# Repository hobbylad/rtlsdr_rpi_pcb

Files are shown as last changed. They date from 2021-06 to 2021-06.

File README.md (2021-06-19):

# rtlsdr_rpi_pcb

##RTL-SDR and Raspberry Pi 3 Carrier PCB 

An RTL-SDR and Raspberry Pi make a good combination. The RTL-SDR has a range of 24MHz-1.7GHz and the RPi 3 enough power to compile and run a wide range of open-source receiver software.

The aim of this carrier PCB is to mechanically combine both SDR and RPi, reduce wiring, allow the control of external devices such as relays and provide power with some expansion capability. Safety, noise and RPI cooling were also considerations.

The board was designed with Kicad on a single-sided board with the aim of keeping the PCB as simple as possible for hobbyists to construct with chemical etching or a milling machine.

See the [blog page for this project](https://hobbylad.wordpress.com/2021/06/17/rtl-sdr-raspberry-pi-carrier-pcb/).

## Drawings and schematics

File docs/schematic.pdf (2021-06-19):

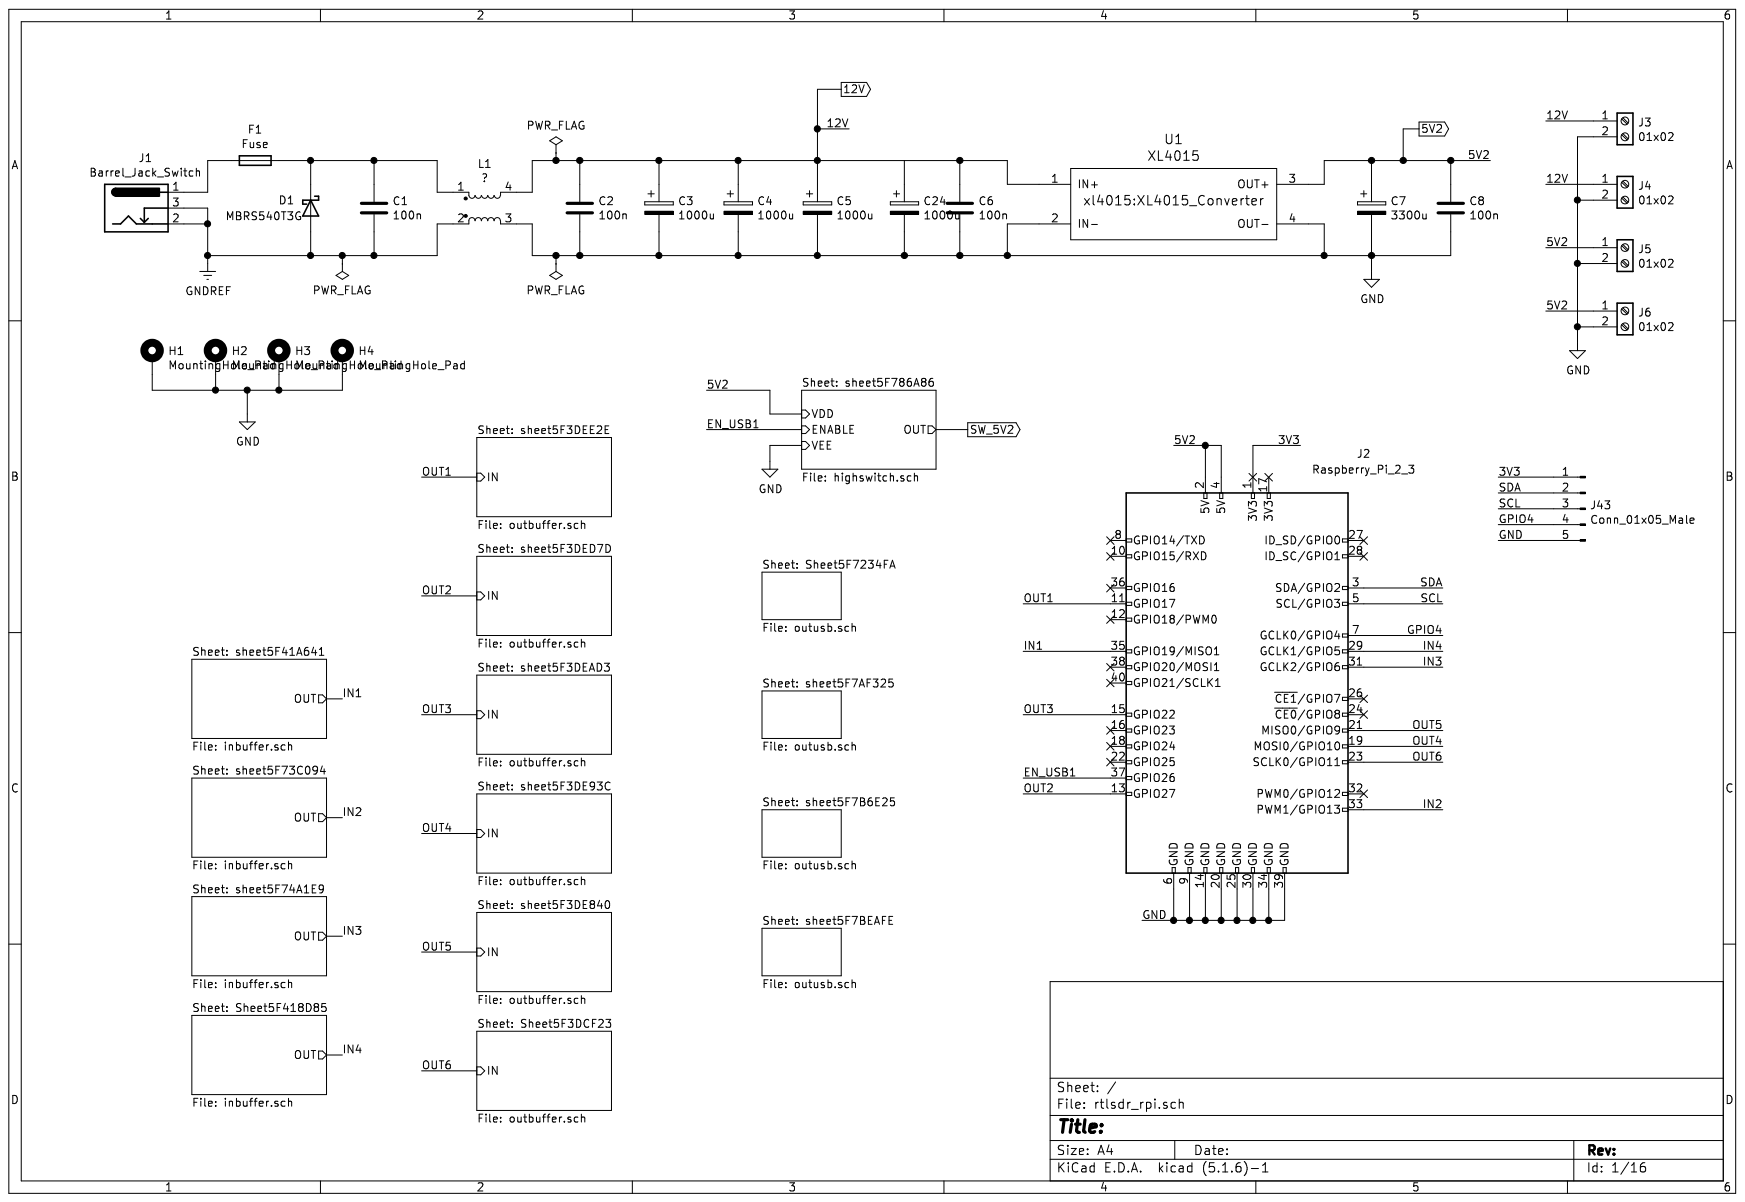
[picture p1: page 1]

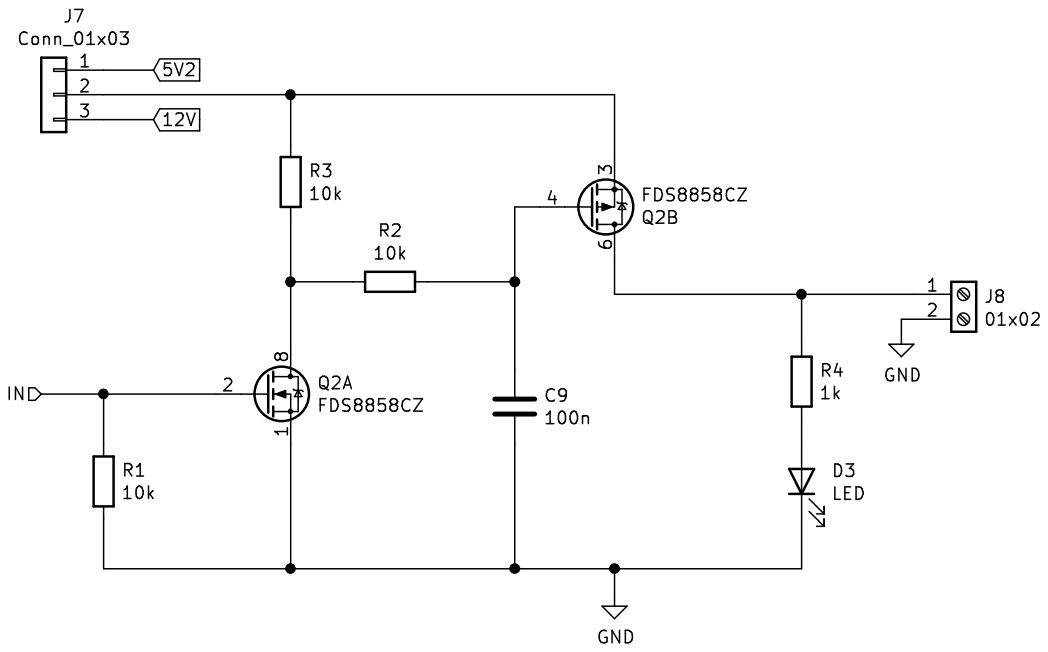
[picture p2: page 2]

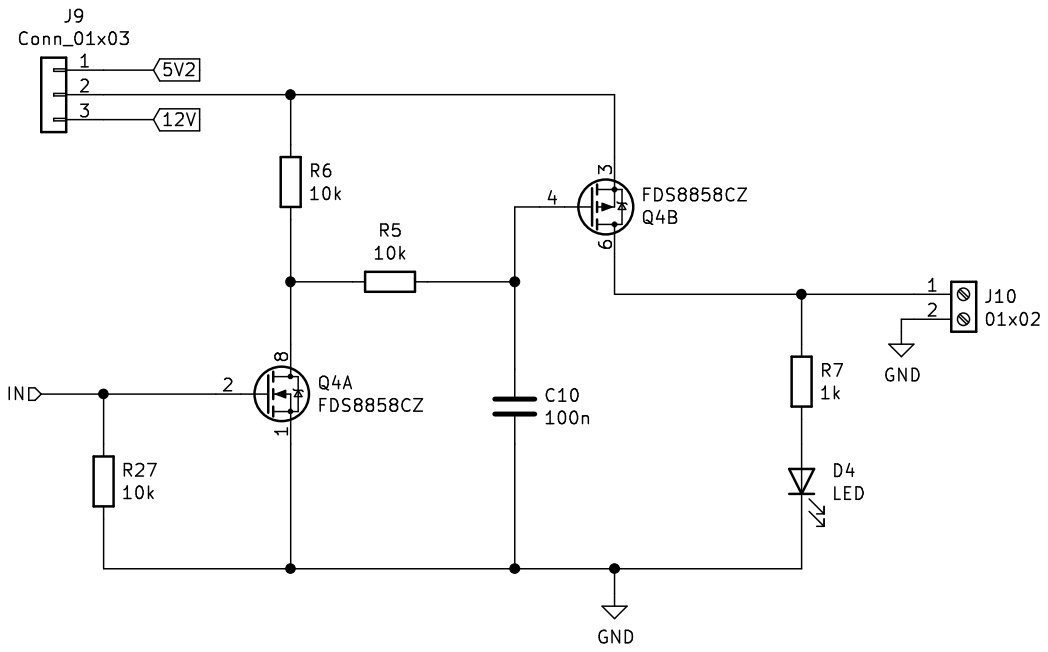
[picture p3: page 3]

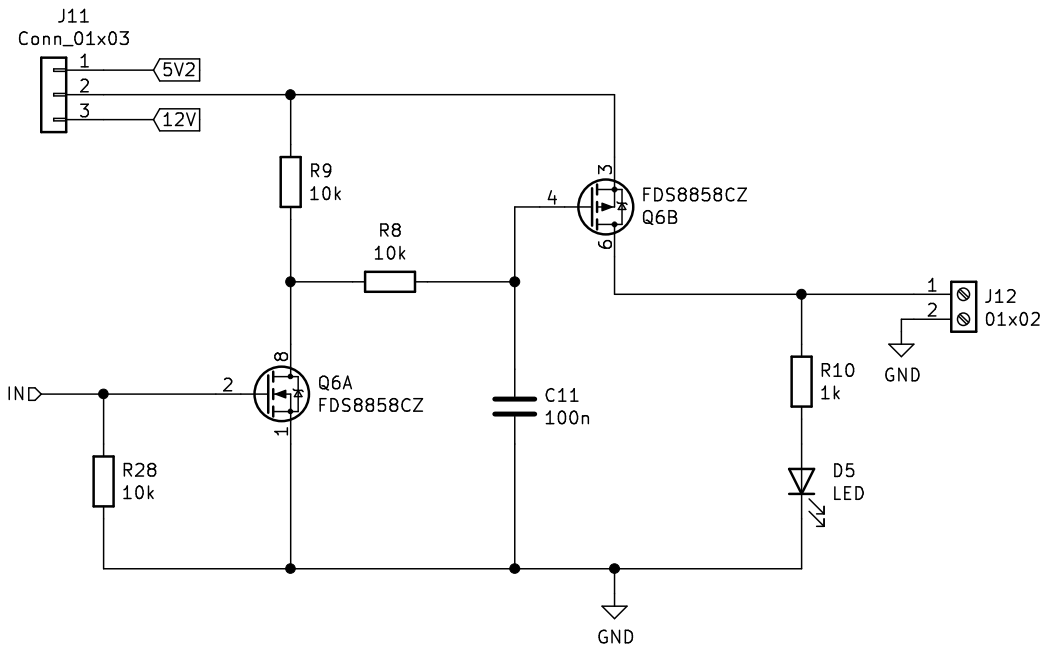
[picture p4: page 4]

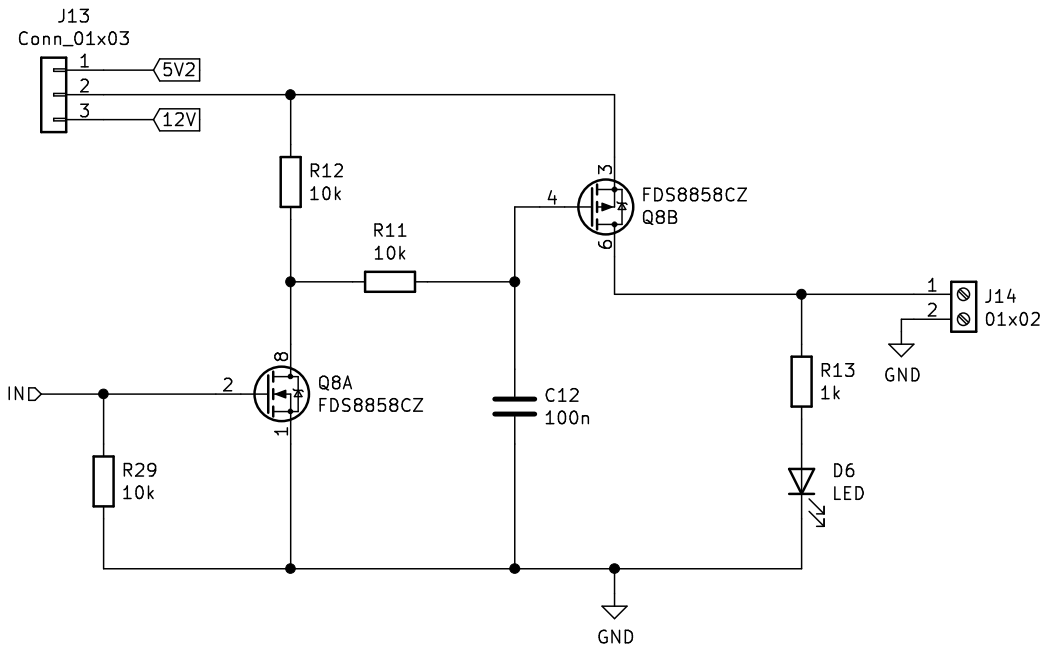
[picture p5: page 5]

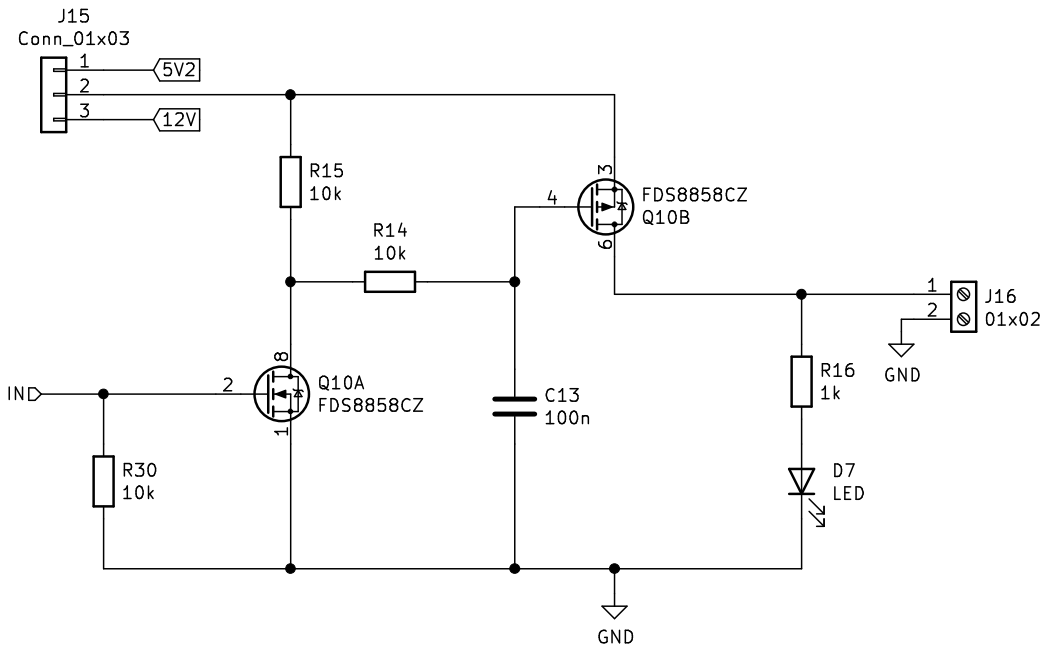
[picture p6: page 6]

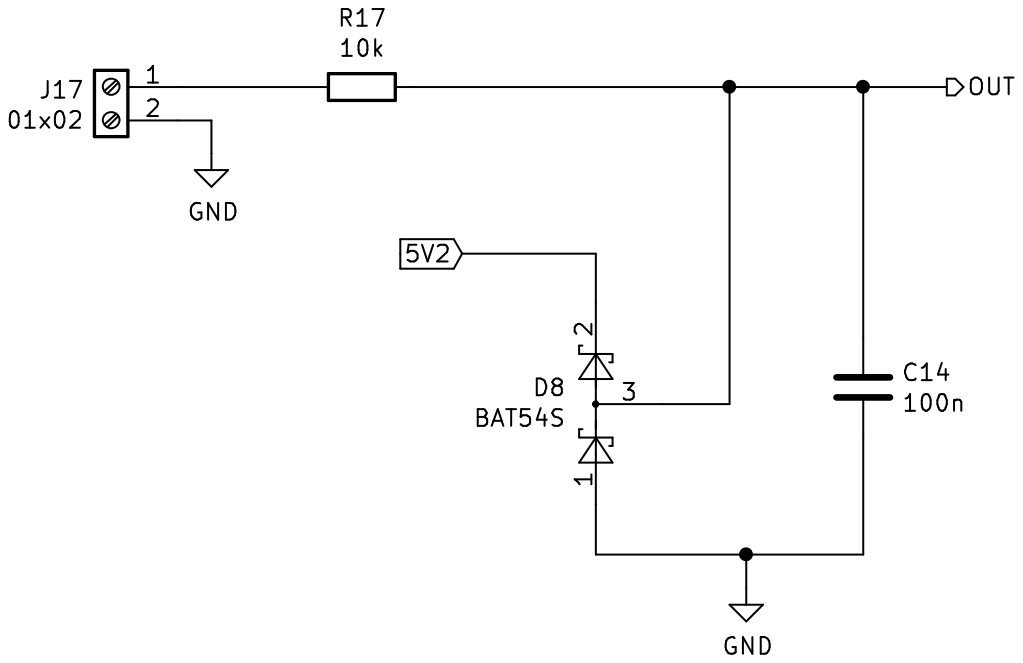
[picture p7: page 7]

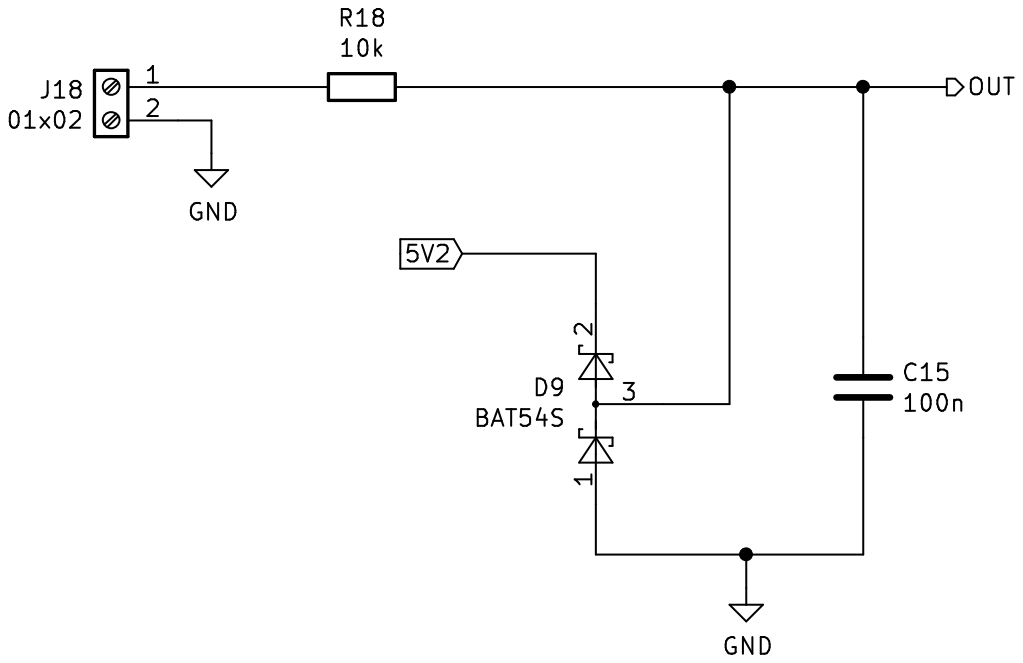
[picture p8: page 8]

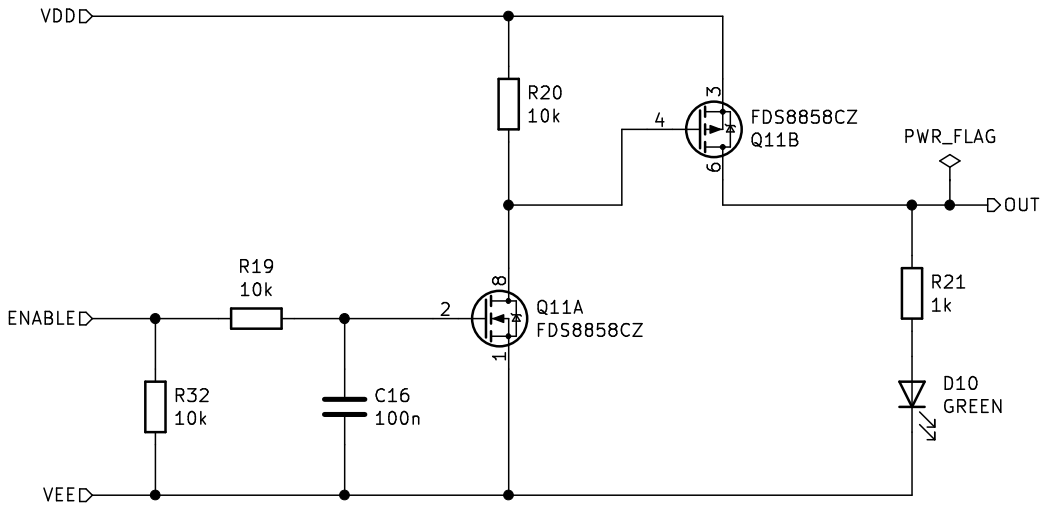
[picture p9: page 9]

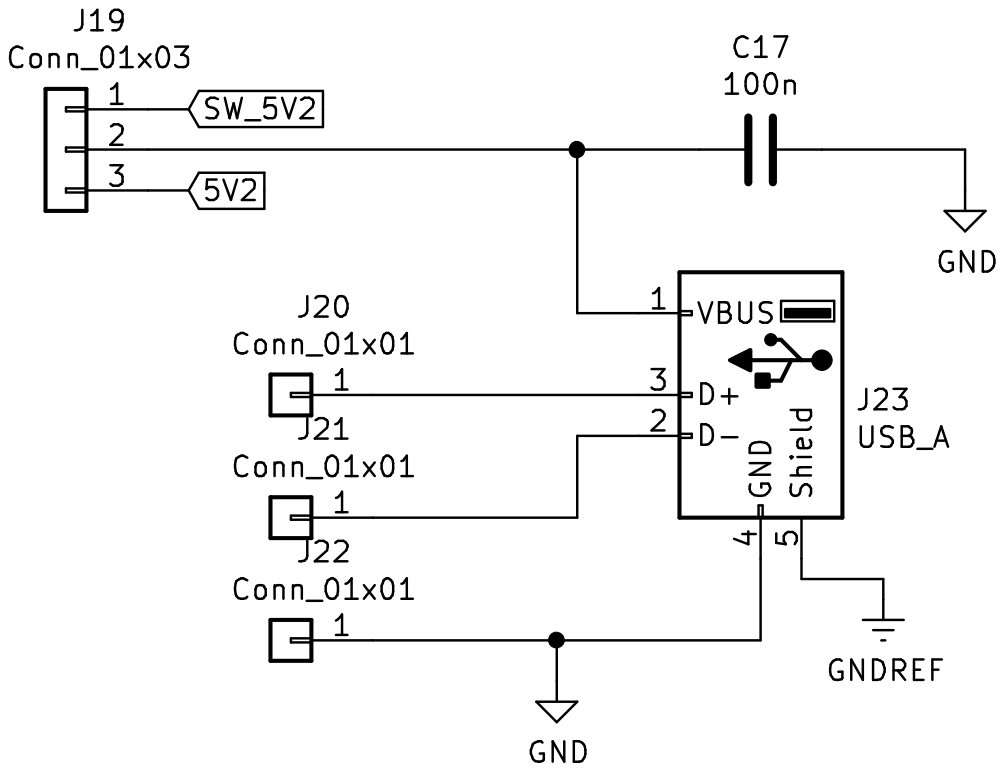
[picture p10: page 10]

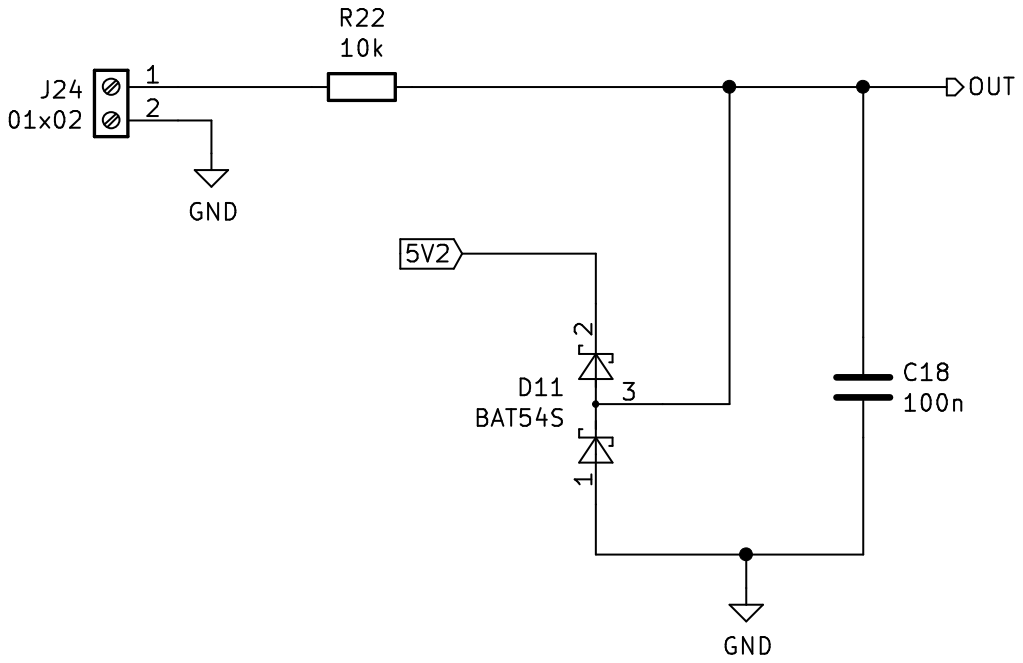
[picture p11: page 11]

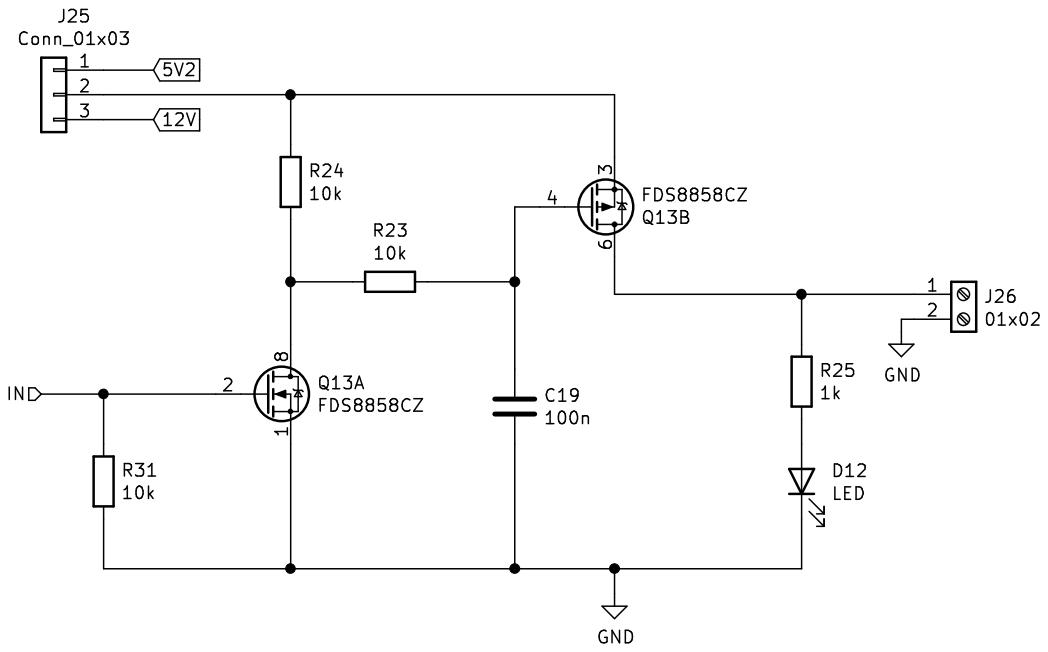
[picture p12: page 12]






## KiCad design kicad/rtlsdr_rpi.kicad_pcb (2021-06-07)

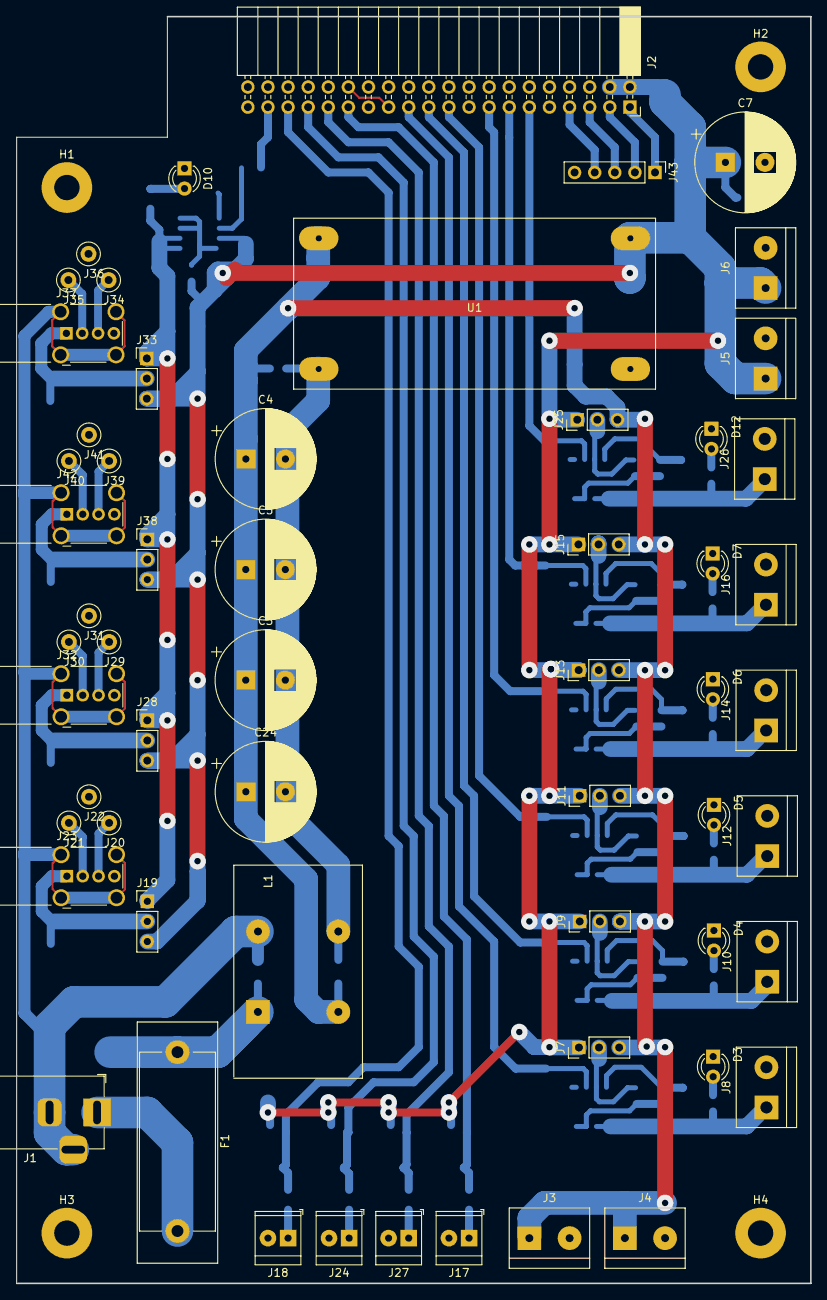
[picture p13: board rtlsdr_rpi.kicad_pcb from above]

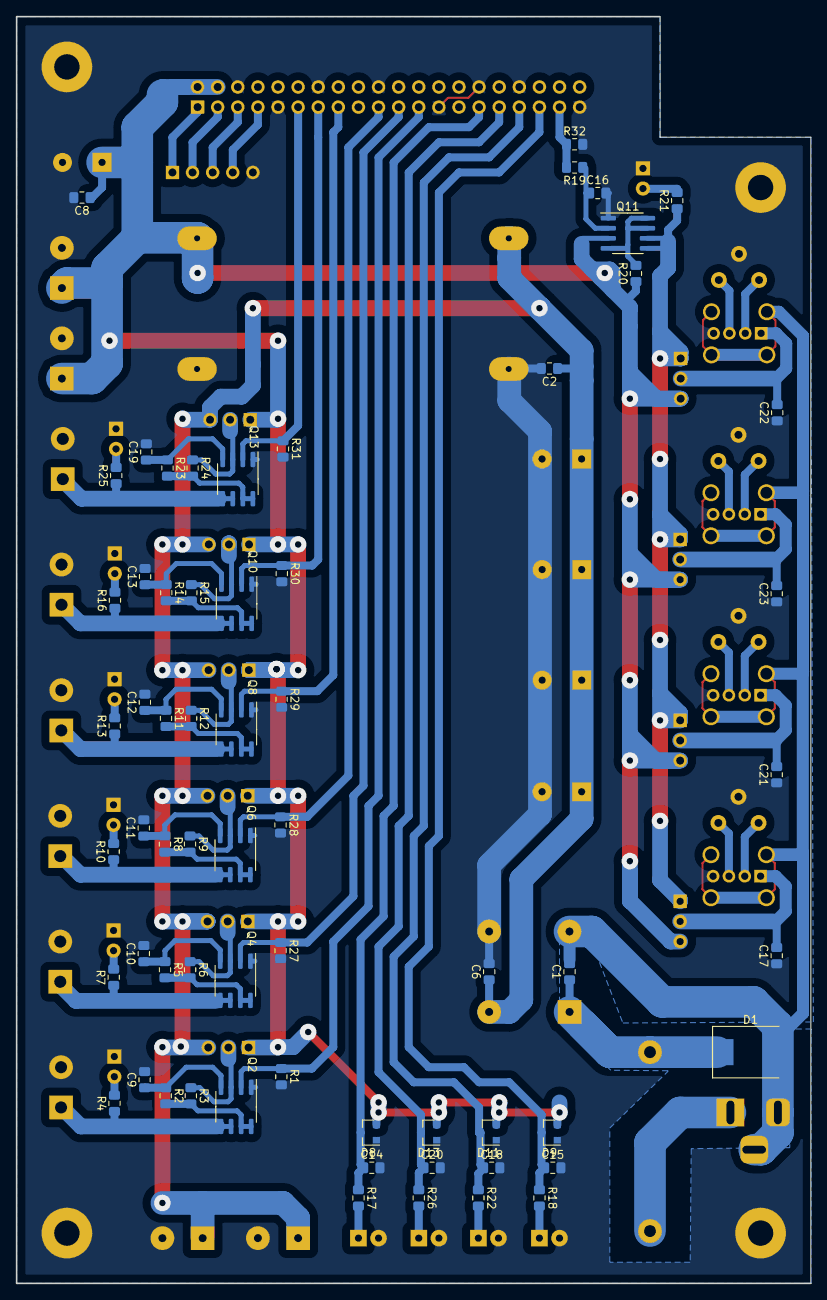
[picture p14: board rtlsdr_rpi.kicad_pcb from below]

Board: 2 copper layers, 100.3 x 160.0 mm, 125 parts (63 on the bottom side), 71 nets.

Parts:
C1, C2, C6, C8, C9, C10, C11, C12, C13, C14, C15, C16, C17, C18, C19, C20, C21, C22, C23: 100n; C_0805_2012Metric_Pad1.15x1.40mm_HandSolder
C3, C4, C5, C24: 1000u; CP_Radial_D12.5mm_P5.00mm
C7: 3300u; CP_Radial_D12.5mm_P5.00mm
D1: MBRS540T3G; D_SMC
D3, D4, D5, D6, D7, D12: LED; LED_D3.0mm
D8, D9, D11, D13: BAT54S; SOT-23
D10: GREEN; LED_D3.0mm
F1: Fuse; Fuseholder_Cylinder-5x20mm_Stelvio-Kontek_PTF78_Horizontal_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
H1, H2, H3, H4: MountingHole_Pad; MountingHole_3.2mm_M3_Pad
J1: Barrel_Jack_Switch; BarrelJack_Horizontal
J2: Raspberry_Pi_2_3; PinSocket_2x20_P2.54mm_Horizontal
J3, J4, J5, J6, J8, J10, J12, J14, J16, J26: 01x02; TerminalBlock_bornier-2_P5.08mm
J7, J9, J11, J13, J15, J19, J25, J28, J33, J38: Conn_01x03; PinHeader_1x03_P2.54mm_Vertical
J17, J18, J24, J27: 01x02; TerminalBlock_TE_282834-2_1x02_P2.54mm_Horizontal
J20, J21, J22, J29, J30, J31, J34, J35, J36, J39, J40, J41: Conn_01x01; TestPoint_Loop_D2.50mm_Drill1.0mm_LowProfile
J23, J32, J37, J42: USB_A; USB_A_Wuerth_614004134726_Horizontal
J43: Conn_01x05_Male; PinHeader_1x05_P2.54mm_Vertical
L1: ?; L_CommonMode_Toroid_Vertical_L26mm_W12mm_Px10mm_Py10mm_Ebay
Q2, Q4, Q6, Q8, Q10, Q11, Q13: FDS8858CZ; SOIC-8_3.9x4.9mm_P1.27mm
R1, R2, R3, R5, R6, R8, R9, R11, R12, R14, R15, R17, R18, R19, R20, R22, R23, R24, R26, R27, R28, R29, R30, R31, R32: 10k; R_0805_2012Metric_Pad1.15x1.40mm_HandSolder
R4, R7, R10, R13, R16, R21, R25: 1k; R_0805_2012Metric_Pad1.15x1.40mm_HandSolder
U1: XL4015; XL4015_Converter

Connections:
5V2: C7.1, C8.1, D8.2, D9.2, D11.2, D13.2, J2.2, J2.4, J5.1, J6.1, J7.1, J9.1, J11.1, J13.1, J15.1, J19.3, J25.1, J28.3, J33.3, J38.3, Q11.3, R20.1, U1.3
12V: C2.1, C3.1, C4.1, C5.1, C6.1, J3.1, J4.1, J7.3, J9.3, J11.3, J13.3, J15.3, J25.3, L1.4, U1.1
/3V3: J2.1, J43.1
/EN_USB1: J2.37, R19.2, R32.1
/GPIO4: J2.7, J43.4
/IN1: C15.1, D9.3, J2.35, R18.1
/IN2: C18.1, D11.3, J2.33, R22.1
/IN3: C20.1, D13.3, J2.31, R26.1
/IN4: C14.1, D8.3, J2.29, R17.1
/OUT1: J2.11, Q13.2, R31.1
/OUT2: J2.13, Q10.2, R30.1
/OUT3: J2.15, Q8.2, R29.1
/OUT4: J2.19, Q6.2, R28.1
/OUT5: J2.21, Q4.2, R27.1
/OUT6: J2.23, Q2.2, R1.1
/SCL: J2.5, J43.3
/SDA: J2.3, J43.2
GND: C2.2, C3.2, C4.2, C5.2, C6.2, C7.2, C8.2, C9.2, C10.2, C11.2, C12.2, C13.2, C14.2, C15.2, C16.2, C17.1, C18.2, C19.2, C20.2, C21.1, C22.1, C23.1, C24.2, D3.1, D4.1, D5.1, D6.1, D7.1, D8.1, D9.1, D10.1, D11.1, D12.1, D13.1, H1.1, H2.1, H3.1, H4.1, J2.6, J2.9, J2.14, J2.20, J2.25, J2.30, J2.34, J2.39, J3.2, J4.2, J5.2, J6.2, J8.2, J10.2, J12.2, J14.2, J16.2, J17.2, J18.2, J22.1, J23.4, J24.2, J26.2, J27.2, J31.1, J32.4, J36.1, J37.4, J41.1, J42.4, J43.5, L1.3, Q2.1, Q4.1, Q6.1, Q8.1, Q10.1, Q11.1, Q13.1, R1.2, R27.2, R28.2, R29.2, R30.2, R31.2, R32.2, U1.2, U1.4
GNDREF: C1.2, D1.2, J1.2, J1.3, J23.5, J32.5, J37.5, J42.5, L1.2
unnamed: C1.1, D1.1, F1.1, L1.1
unnamed: C9.1, Q2.4, R2.1
unnamed: C10.1, Q4.4, R5.1
unnamed: C11.1, Q6.4, R8.1
unnamed: C12.1, Q8.4, R11.1
unnamed: C13.1, Q10.4, R14.1
unnamed: C16.1, Q11.2, R19.1
unnamed: C17.2, J19.2, J23.1
unnamed: C19.1, Q13.4, R23.1
unnamed: C21.2, J28.2, J32.1
unnamed: C22.2, J33.2, J37.1
unnamed: C23.2, J38.2, J42.1
unnamed: D3.2, R4.2
unnamed: D4.2, R7.2
unnamed: D5.2, R10.2
unnamed: D6.2, R13.2
unnamed: D7.2, R16.2
unnamed: D10.2, R21.2
unnamed: D12.2, R25.2
unnamed: F1.2, J1.1
unnamed: J7.2, Q2.3, R3.1
unnamed: J8.1, Q2.5, Q2.6, R4.1
unnamed: J9.2, Q4.3, R6.1
unnamed: J10.1, Q4.5, Q4.6, R7.1
unnamed: J11.2, Q6.3, R9.1
unnamed: J12.1, Q6.5, Q6.6, R10.1
unnamed: J13.2, Q8.3, R12.1
unnamed: J14.1, Q8.5, Q8.6, R13.1
unnamed: J15.2, Q10.3, R15.1
unnamed: J16.1, Q10.5, Q10.6, R16.1
unnamed: J17.1, R17.2
unnamed: J18.1, R18.2
unnamed: J20.1, J23.3
unnamed: J21.1, J23.2
unnamed: J24.1, R22.2
unnamed: J25.2, Q13.3, R24.1
unnamed: J26.1, Q13.5, Q13.6, R25.1
unnamed: J27.1, R26.2
unnamed: J29.1, J32.3
unnamed: J30.1, J32.2
unnamed: J34.1, J37.3
unnamed: J35.1, J37.2
unnamed: J39.1, J42.3
unnamed: J40.1, J42.2
unnamed: Q2.7, Q2.8, R2.2, R3.2
unnamed: Q4.7, Q4.8, R5.2, R6.2
unnamed: Q6.7, Q6.8, R8.2, R9.2
unnamed: Q8.7, Q8.8, R11.2, R12.2
unnamed: Q10.7, Q10.8, R14.2, R15.2
unnamed: Q11.4, Q11.7, Q11.8, R20.2
unnamed: Q13.7, Q13.8, R23.2, R24.2
SW_5V2: J19.1, J28.1, J33.1, J38.1, Q11.5, Q11.6, R21.1

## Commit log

2021-06-07 Initial schematic and layout.
    [highswitch.sch, inbuffer.sch, outbuffer.sch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]
2021-06-19 Added schmetic and layout drawing of prototype board.
